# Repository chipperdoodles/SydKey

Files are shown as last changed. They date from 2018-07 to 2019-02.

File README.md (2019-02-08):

# SydKey
Kicad files for a 4x6 numbpad using bluefruit 32u4 feather

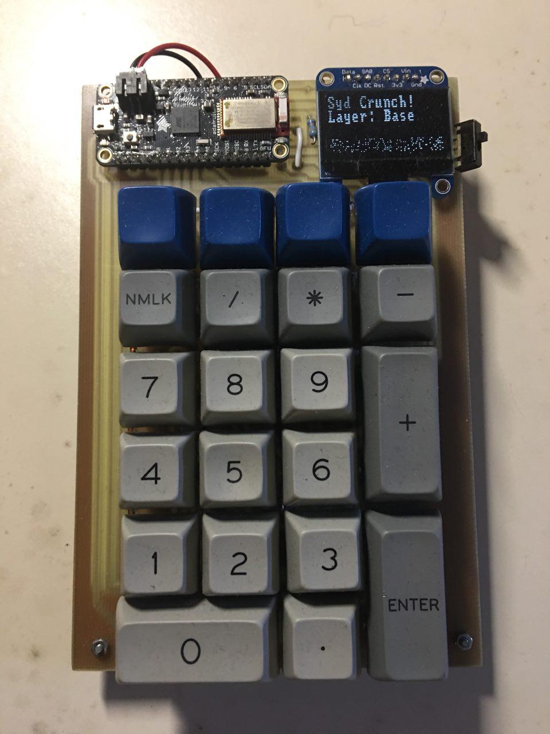
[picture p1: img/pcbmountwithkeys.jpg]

	
### Design
This is a dead simple design is to make a bluetooth/qmk compatible number pad with small oled screen. It has 4 function keys and a full number pad layout underneath, it does not support alps switches or alternate layouts.

It was designed with my home workflow in mind. This involves being etched via tiny cheap cnc engraver, hand soldered and then programmed via QMK. Trace width and pad shapes were messed with to make hand soldering more forgivable. It's also designed with the intention of one side being traced and the other side being hand wired, I found in my struggles with my aligning front and back designs in the process.

### BOM
* 6x4 Copper Clad Board
* Diodes
* Cherry Mx compatible switches
* i2c Oled (I used the adafruit 128x64)
* Adafruit Bluefruit 32u4 Feather

### Programming
The board is programmed using the open source firmware QMK, its quite excellent and though I may not be a great programmer, their documentation covers the essential basics and with examples I pulled together some code to get it functioning. However, I know someone can do much better! See more in the QMK code folder.

### Versioning
* V.02 - Added pull up resistors however I think I did them wrong.
* V.01 - Functioning prototype

### TODO
* Fix old kicad diode in schematics so the proper pin is selected in the pcb. Currently on the pcb the diode direction is reversed from how you actually want to solder them.
* Program ios/android shortcuts/clean up default keymap

### Resources
* Kicad
* Regack's 4x6 numbpad
* adafruit kicad lib
* teensy kicad lib
* geekhack forums
* input club design files
* deskauthority wiki

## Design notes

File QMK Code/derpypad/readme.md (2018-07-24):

#Derpypad

##About
Derpypad is a home milled, half hand wired, bluetooth numberpad made to work
Adafruit's 32u4 Bluefruit Feather. There are some current problems with the bluetooth (not sure if firmware or my end) but it's mostly functional.

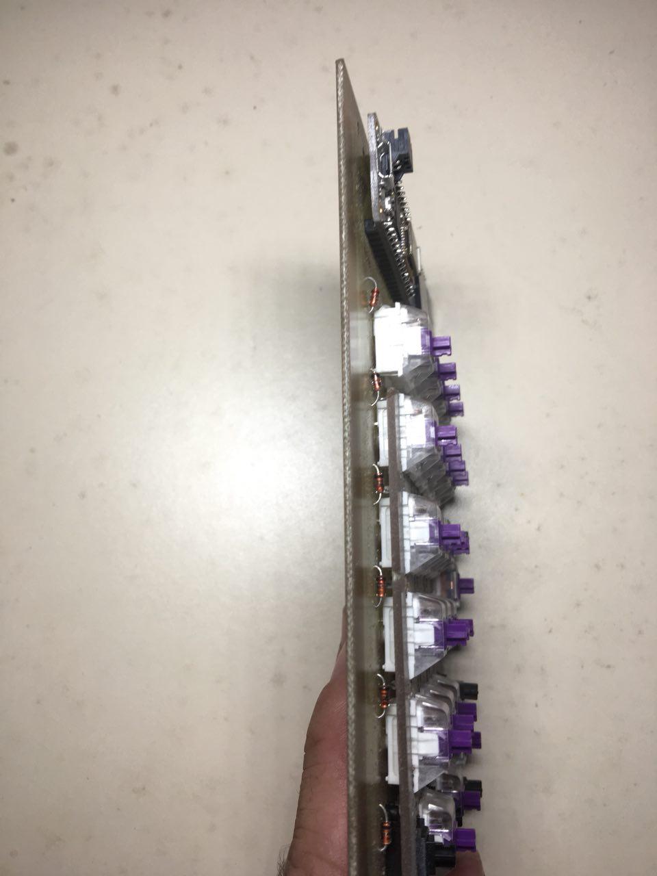
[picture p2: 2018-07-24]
img/platemountside.jpg

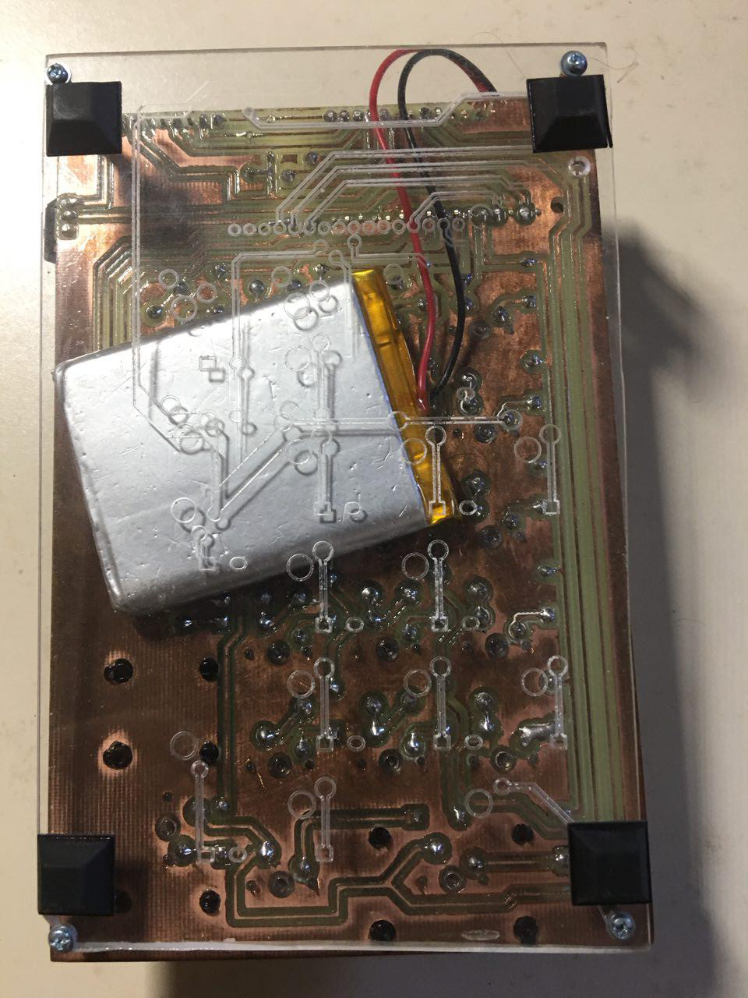
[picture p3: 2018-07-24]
img/pcbmountbottom.jpg

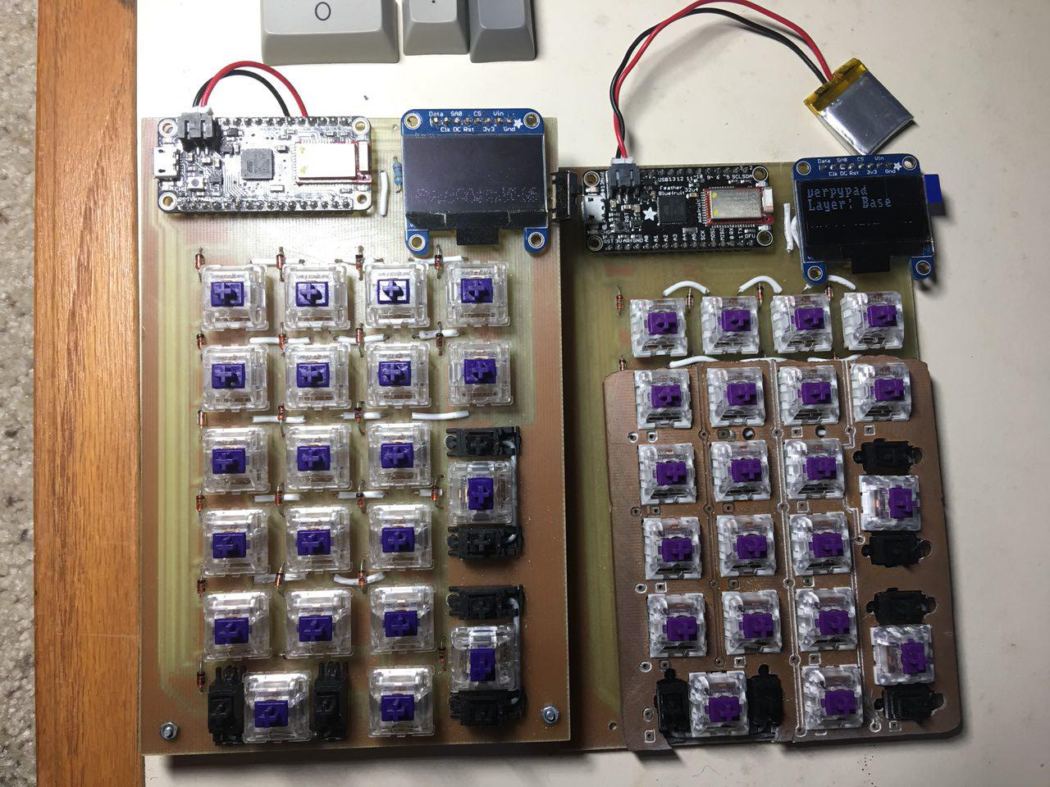
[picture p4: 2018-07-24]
img/SideBySide.jpg

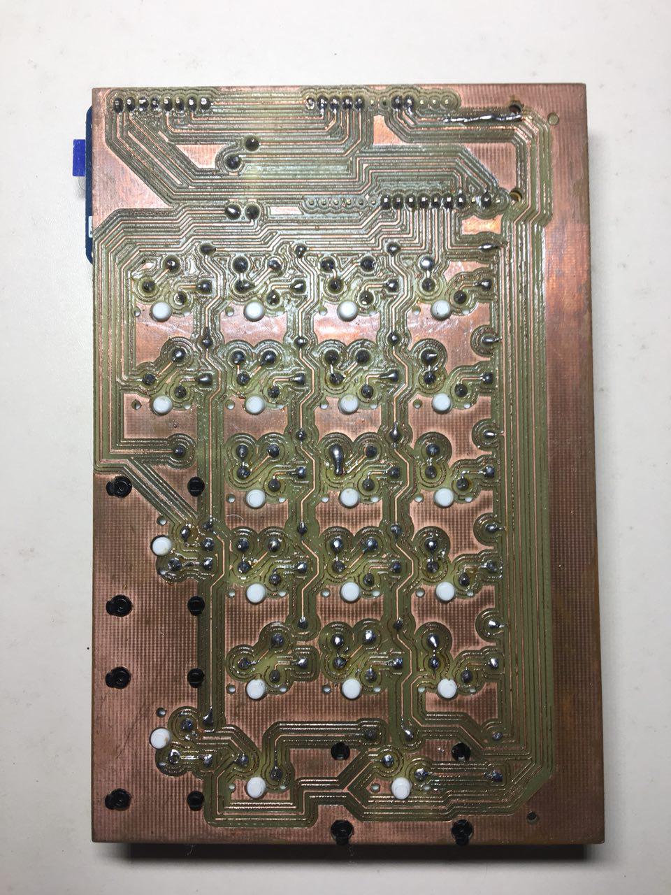
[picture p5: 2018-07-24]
img/platemountbottom.jpg

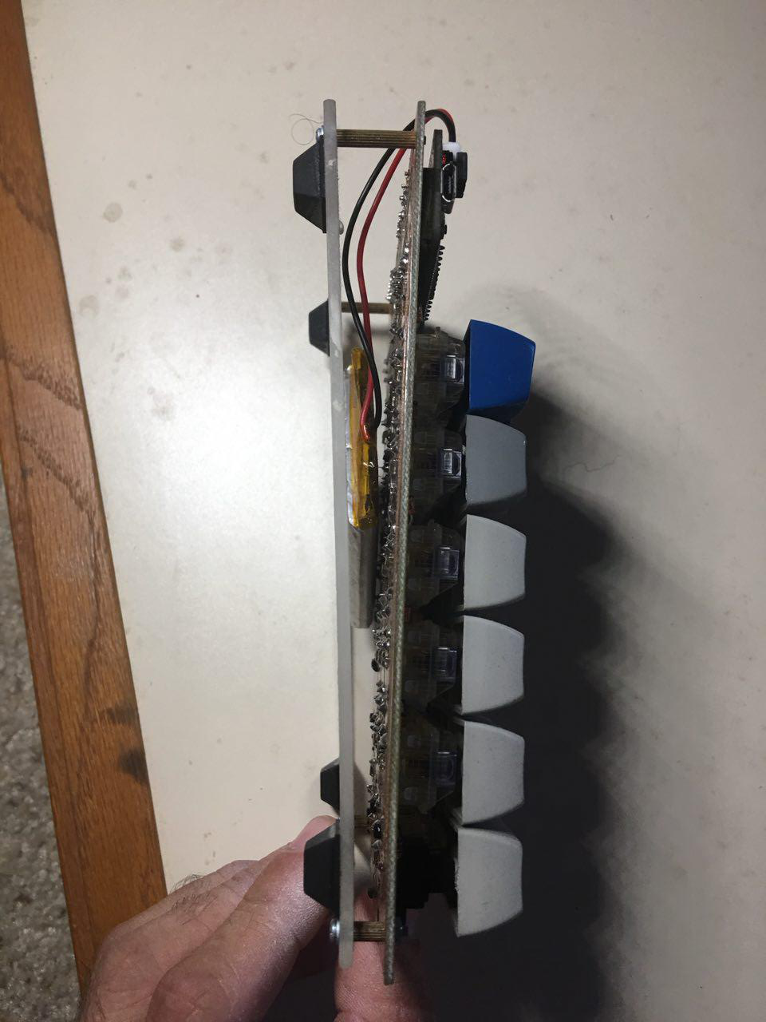
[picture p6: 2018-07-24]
img/pcbmountside.jpg

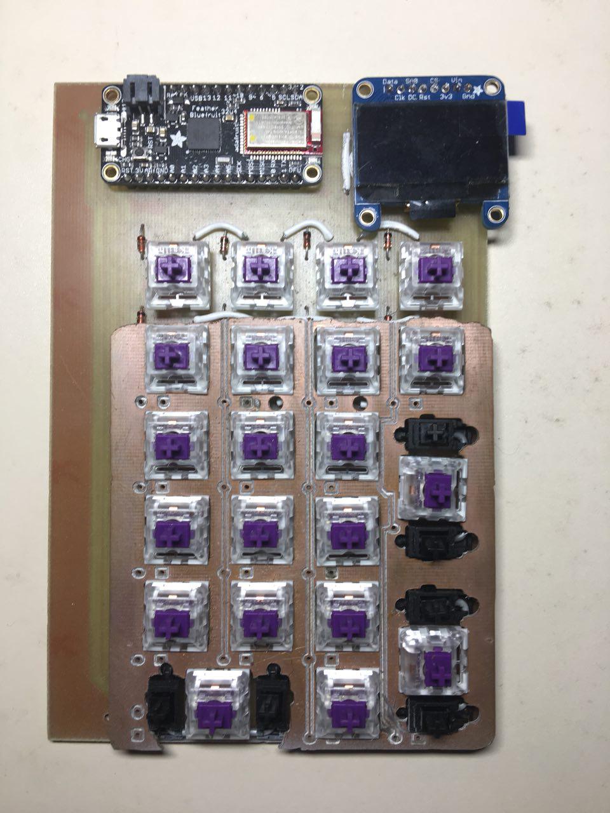
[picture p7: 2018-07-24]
img/platemounttop.jpg

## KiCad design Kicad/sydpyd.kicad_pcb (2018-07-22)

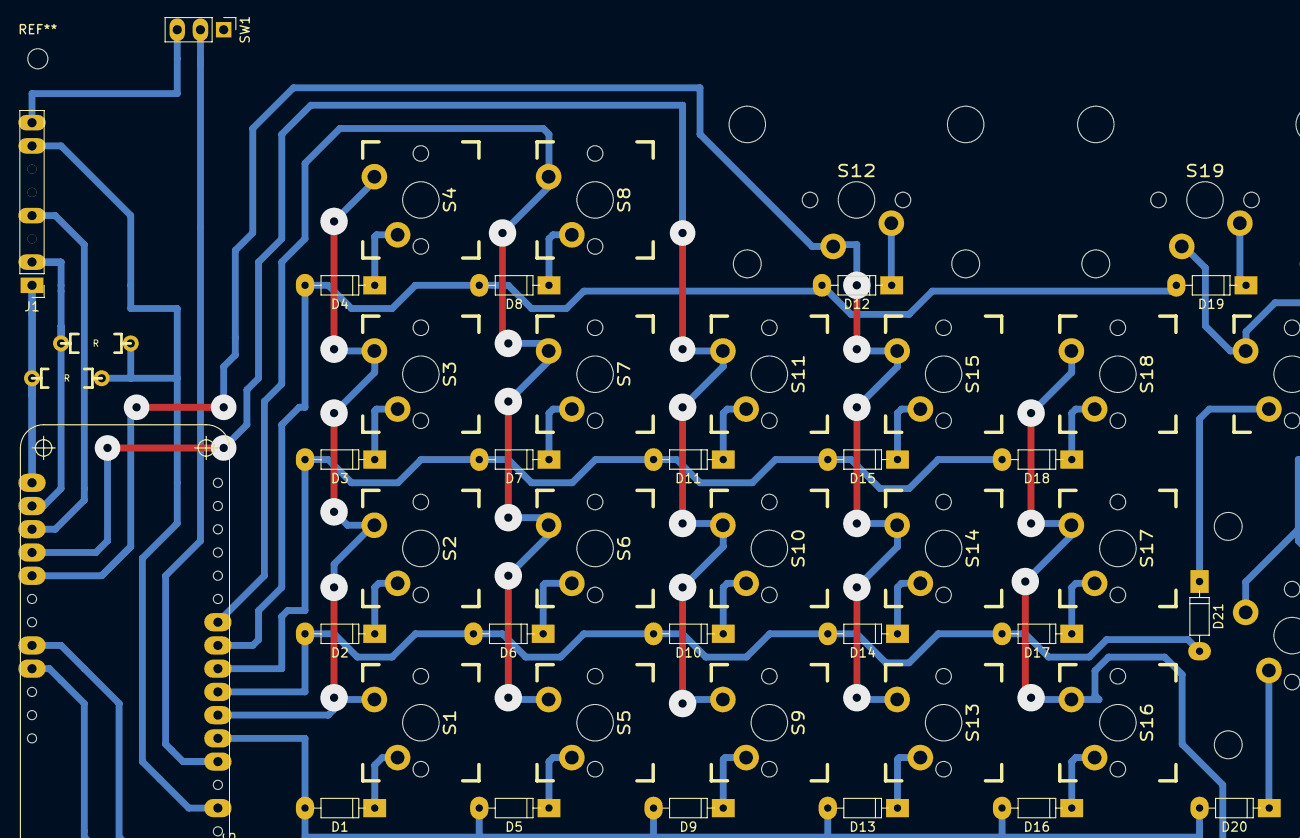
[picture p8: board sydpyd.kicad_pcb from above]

Board: 2 copper layers, 47 parts (0 on the bottom side), 37 nets.

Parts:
D1, D2, D3, D4, D5, D6, D7, D8, D9, D10, D11, D12, D13, D14, D15, D16, D17, D18, D19, D20, D21: 1N4148; D_DO-35_SOD27_P7.62mm_Horizontal
J1: OLED; Socket_Strip_Straight_1x08_Pitch2.54mm
MS1: FEATHERWING
R1, R2: R; Resistor_THT
S1, S2, S3, S4, S5, S6, S7, S8, S9, S10, S11, S13, S14, S15, S16, S17, S18, S21: MX1A; CHERRY_PCB_100H
S12, S19, S20: MX1A; CHERRY_PCB_200H
SW1: SW_DPDT_x2; Socket_Strip_Straight_1x03_Pitch2.54mm

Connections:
/SCL: J1.2, MS1.18, R2.2
/SDA: J1.1, MS1.17, R1.1
/col1: D1.2, D5.2, D9.2, D13.2, D16.2, D20.2, MS1.5
/col2: D2.2, D6.2, D10.2, D14.2, D17.2, D21.2, MS1.7
/col3: D3.2, D7.2, D11.2, D15.2, D18.2, MS1.8
/col4: D4.2, D8.2, D12.2, D19.2, MS1.9
/row1: MS1.6, S1.1, S2.1, S3.1, S4.1
/row2: MS1.10, S5.1, S6.1, S7.1, S8.1
/row3: MS1.20, S9.1, S10.1, S11.1
/row4: MS1.21, S12.1, S13.1, S14.1, S15.1
/row5: MS1.24, S16.1, S17.1, S18.1
/row6: MS1.25, S19.1, S20.1, S21.1
/~RES~: J1.4, MS1.19
GND: MS1.4, SW1.2
unnamed: D1.1, S1.2
unnamed: D2.1, S2.2
unnamed: D3.1, S3.2
unnamed: D4.1, S4.2
unnamed: D5.1, S5.2
unnamed: D6.1, S6.2
unnamed: D7.1, S7.2
unnamed: D8.1, S8.2
unnamed: D9.1, S9.2
unnamed: D10.1, S10.2
unnamed: D11.1, S11.2
unnamed: D12.1, S12.2
unnamed: D13.1, S13.2
unnamed: D14.1, S14.2
unnamed: D15.1, S15.2
unnamed: D16.1, S16.2
unnamed: D17.1, S17.2
unnamed: D18.1, S18.2
unnamed: D19.1, S19.2
unnamed: D20.1, S20.2
unnamed: D21.1, S21.2
unnamed: J1.8, SW1.3
VCC: J1.7, MS1.2, R1.2, R2.1

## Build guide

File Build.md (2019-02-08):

# intructions for build

## Milling
 This board is meant to be milled onto one sides copper clad board, You'll only need to mill the back side. A very important thing to note is that the image must be mirrored along the x axis (in the design the board is on it's side). You can do the mirroring in flatcam while preparing for export to gcode.
## Soldering
Start by soldering the diodes in first, technically you can choose to solder them on the switch side or the reverse side, In my prototype boards i soldered them switch side since it would be easier to solder the legs that way.
After you solder the diodes i would solder in the jumper cables. I Cut some solid core wire and connected the gaps via them. You can use the kicad frontside traces as a guide on where to wire the jumpers. It's designed using big fake vias as throughhole points for the jumpers.

## Case and Plate Making

## Firmware
The firmware is qmk heavily derived from other projects which i compiled locally via windows subsystem for linux and flashed using QMK Toolbox.

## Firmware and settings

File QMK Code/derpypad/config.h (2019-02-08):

#ifndef CONFIG_H
#define CONFIG_H

#include "config_common.h"

/* USB Device descriptor parameter */
#define VENDOR_ID       0xFEED
#define PRODUCT_ID      0x6060
#define DEVICE_VER      0x0001
#define MANUFACTURER    qmkbuilder
#define PRODUCT         DerpyPad
#define DESCRIPTION     DIY BLE Keypad
#define CATERINA_BOOTLOADER

/* key matrix size */
#define MATRIX_ROWS 6
#define MATRIX_COLS 4

/* key matrix pins */
#define MATRIX_ROW_PINS { F6, F0, D7, B5, D6, C7 }
#define MATRIX_COL_PINS { F7, F5, F4, F1 }
#define UNUSED_PINS

/* COL2ROW or ROW2COL */
#define DIODE_DIRECTION ROW2COL

#define USE_I2C
#define SSD1306OLED
//#define OLED_ROTATE180
#define SSD1306_ADDRESS 0x3D
#define ADAFRUIT_BLE_ENABLE

/* Set 0 if debouncing isn't needed */
#define DEBOUNCING_DELAY 5

/* Mechanical locking support. Use KC_LCAP, KC_LNUM or KC_LSCR instead in keymap */
#define LOCKING_SUPPORT_ENABLE

/* Locking resynchronize hack */
#define LOCKING_RESYNC_ENABLE

/* key combination for command */
#define IS_COMMAND() ( \
    keyboard_report->mods == (MOD_BIT(KC_LSHIFT) | MOD_BIT(KC_RSHIFT)) \
)

/* prevent stuck modifiers */
#define PREVENT_STUCK_MODIFIERS

#endif

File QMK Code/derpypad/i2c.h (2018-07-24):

#ifndef I2C_H
#define I2C_H

#include <stdint.h>

#ifndef F_CPU
#define F_CPU 8000000UL
#endif

#define I2C_READ 1
#define I2C_WRITE 0

#define I2C_ACK 1
#define I2C_NACK 0

#define SLAVE_BUFFER_SIZE 0x10

// i2c SCL clock frequency
#define SCL_CLOCK  400000L

extern volatile uint8_t i2c_slave_buffer[SLAVE_BUFFER_SIZE];

void i2c_master_init(void);
uint8_t i2c_master_start(uint8_t address);
void i2c_master_stop(void);
uint8_t i2c_master_write(uint8_t data);
uint8_t i2c_master_read(int);
void i2c_reset_state(void);
void i2c_slave_init(uint8_t address);


static inline unsigned char i2c_start_read(unsigned char addr) {
  return i2c_master_start((addr << 1) | I2C_READ);
}

static inline unsigned char i2c_start_write(unsigned char addr) {
  return i2c_master_start((addr << 1) | I2C_WRITE);
}

// from SSD1306 scrips
extern unsigned char i2c_rep_start(unsigned char addr);
extern void i2c_start_wait(unsigned char addr);
extern unsigned char i2c_readAck(void);
extern unsigned char i2c_readNak(void);
extern unsigned char i2c_read(unsigned char ack);

#define i2c_read(ack)  (ack) ? i2c_readAck() : i2c_readNak();

#endif
